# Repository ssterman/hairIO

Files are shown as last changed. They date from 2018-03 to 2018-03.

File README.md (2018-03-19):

# HairIO

Human hair is a cultural material, with a rich history displaying individuality, cultural expression and group identity.  It is malleable in length,  color and style,  highly visible,  and embedded in a range of personal and group interactions. As wearable technologies move ever closer to the body, and embodied interactions become more common and desirable, hair presents a unique and little-explored site for novel interactions. In this paper, we present an exploration and working prototype of hair as a site for novel interaction, leveraging its position as something both public and private,  social and personal, malleable and permanent. We develop applications and interactions around this new material in HäirIÖ: a novel integration of hair-based technologies and braids that combine capacitive touch input and dynamic output through color and shape change. Finally, we evaluate this hair-based interactive technology with users, including the integration of HäirIÖ within the landscape of existing wearable and mobile technologies.

Work by: Christine Dierk, Sarah Sterman, Molly Jane Nicholas, Eric Paulos

Hybrid Ecologies Lab
hybrid-ecologies.org

[Video](https://www.youtube.com/watch?v=8JV2D7gJ5HI)

[Paper](https://dl.acm.org/citation.cfm?id=3173232)

## Arduino sketches

In this repo you will find example sketches for use on the HairIO PCB, demonstrating capacitive touch, actuation, and bluetooth control.  

*demo_captouch:* A basic sketch showing only capacitive touch sensing with manually defined sensing thresholds. The onboard LED will light when a touch is identified.

*demo_timing*: A basic sketch showing only actuation.  Every period of x seconds, the braid will actuate, then turn off.  The onboard LED will light when the braid is actuating.

*demo_pcb_bluetooth_with_drive_captouch*: All-inclusive demo that uses the Adafruit Bluetooth app to provide touch feedback and control actuation through the bluetooth chip. 

All hardware pins are defined assuming the PCB version of the HairIO circuit, though all pin mappings should be double-checked when you make your own hardware. 

## Eagle Files

In *hairio_full_3* you will find the Eagle schematic and board file for the integrated PCB version of the HairIO circuit. 

## Instructable

For a full description of this project, please see the [Instructable](https://www.instructables.com/id/HairIO-Hair-As-Interactive-Material/)

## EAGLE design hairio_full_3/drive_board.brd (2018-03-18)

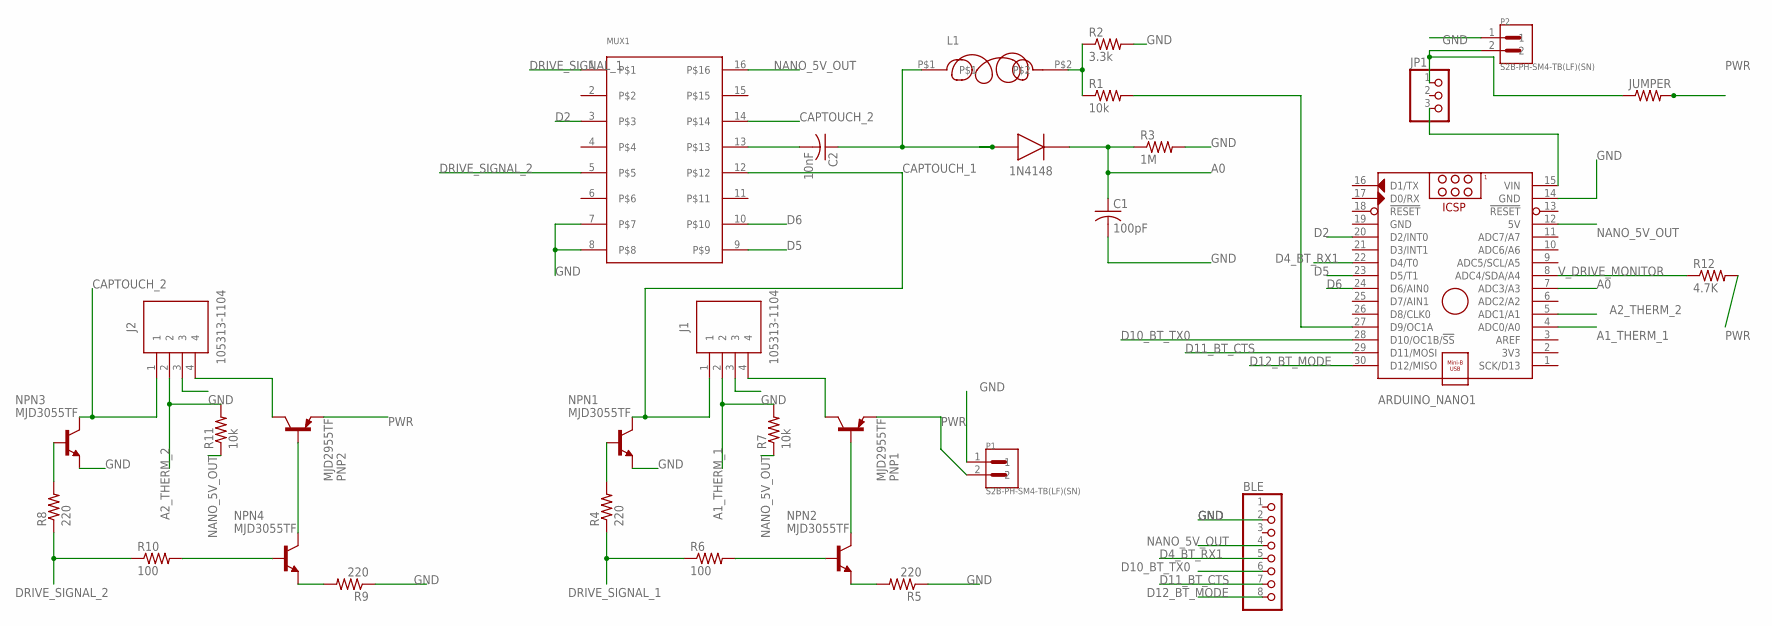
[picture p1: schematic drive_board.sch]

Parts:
1N4148: 1N5819HW-7-F; SOD3716X145N
ARDUINO_NANO1: ARDUINO_NANO
BLE: PINHD-1X8; 1X08
C1: 100pF; C0805
C2: 10nF; C0805
J1, J2: 105313-1104
JP1: PINHD-1X3; 1X03
JUMPER: R-US_R0805; R0805
L1: SRE6603
MUX1: HAIRIO_MUX; SO16
NPN1, NPN2, NPN3, NPN4: MJD3055TF; DPAK
P1, P2: S2B-PH-SM4-TB(LF)(SN); JST_S2B-PH-SM4-TB(LF)(SN)
PNP1, PNP2: MJD2955TF; DPAK
R1, R7, R11: 10k; R0805
R2: 3.3k; R0805
R3: 1M; R0805
R4, R5, R8, R9: 220; R0805
R6, R10: 100; R0805
R12: 4.7K; R0805

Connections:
A0: 1N4148.1 (K), ARDUINO_NANO1.7 (ADC3/A3), C1.1, R3.1
A1_THERM_1: ARDUINO_NANO1.4 (ADC0/A0), J1.2, R7.2
A2_THERM_2: ARDUINO_NANO1.5 (ADC1/A1), J2.2, R11.2
CAPTOUCH_1: J1.1, MUX1.12, NPN1.4 (C)
CAPTOUCH_2: J2.1, MUX1.14, NPN3.4 (C)
D2: ARDUINO_NANO1.20 (D2/INT0), MUX1.3
D4_BT_RX1: ARDUINO_NANO1.22 (D4/T0), BLE.5
D5: ARDUINO_NANO1.23 (D5/T1), MUX1.9
D6: ARDUINO_NANO1.24 (D6/AIN0), MUX1.10
D10_BT_TX0: ARDUINO_NANO1.28 (D10/OC1B/!SS), BLE.6
D11_BT_CTS: ARDUINO_NANO1.29 (D11/MOSI), BLE.7
D12_BT_MODE: ARDUINO_NANO1.30 (D12/MISO), BLE.8
DRIVE_SIGNAL_1: MUX1.1, R4.1, R6.1
DRIVE_SIGNAL_2: MUX1.5, R8.1, R10.1
GND: ARDUINO_NANO1.14 (GND), ARDUINO_NANO1.19 (GND), BLE.2, C1.2, J1.3, J2.3, MUX1.7, MUX1.8, NPN1.3 (E), NPN3.3 (E), P1.1, P2.1, R2.2, R3.2, R5.1, R9.1
unnamed: NPN2.1 (B), R6.2
unnamed: NPN2.3 (E), R5.2
unnamed: NPN4.1 (B), R10.2
unnamed: NPN2.4 (C), PNP1.1 (B)
unnamed: NPN1.1 (B), R4.2
unnamed: C2.2, MUX1.13
unnamed: 1N4148.2 (A), C2.1, L1.P$1
unnamed: J1.4, PNP1.4 (C)
unnamed: ARDUINO_NANO1.27 (D9/OC1A), R1.2
unnamed: L1.P$2, R1.1, R2.1
unnamed: NPN4.3 (E), R9.2
unnamed: ARDUINO_NANO1.15 (VIN), JP1.3
unnamed: NPN4.4 (C), PNP2.1 (B)
unnamed: NPN3.1 (B), R8.2
unnamed: J2.4, PNP2.4 (C)
unnamed: JP1.1, JUMPER.1, P2.2
NANO_5V_OUT: ARDUINO_NANO1.12 (5V), BLE.4, MUX1.16, R7.1, R11.1
PWR: JUMPER.2, P1.2, PNP1.3 (E), PNP2.3 (E), R12.2
V_DRIVE_MONITOR: ARDUINO_NANO1.8 (ADC4/SDA/A4), R12.1

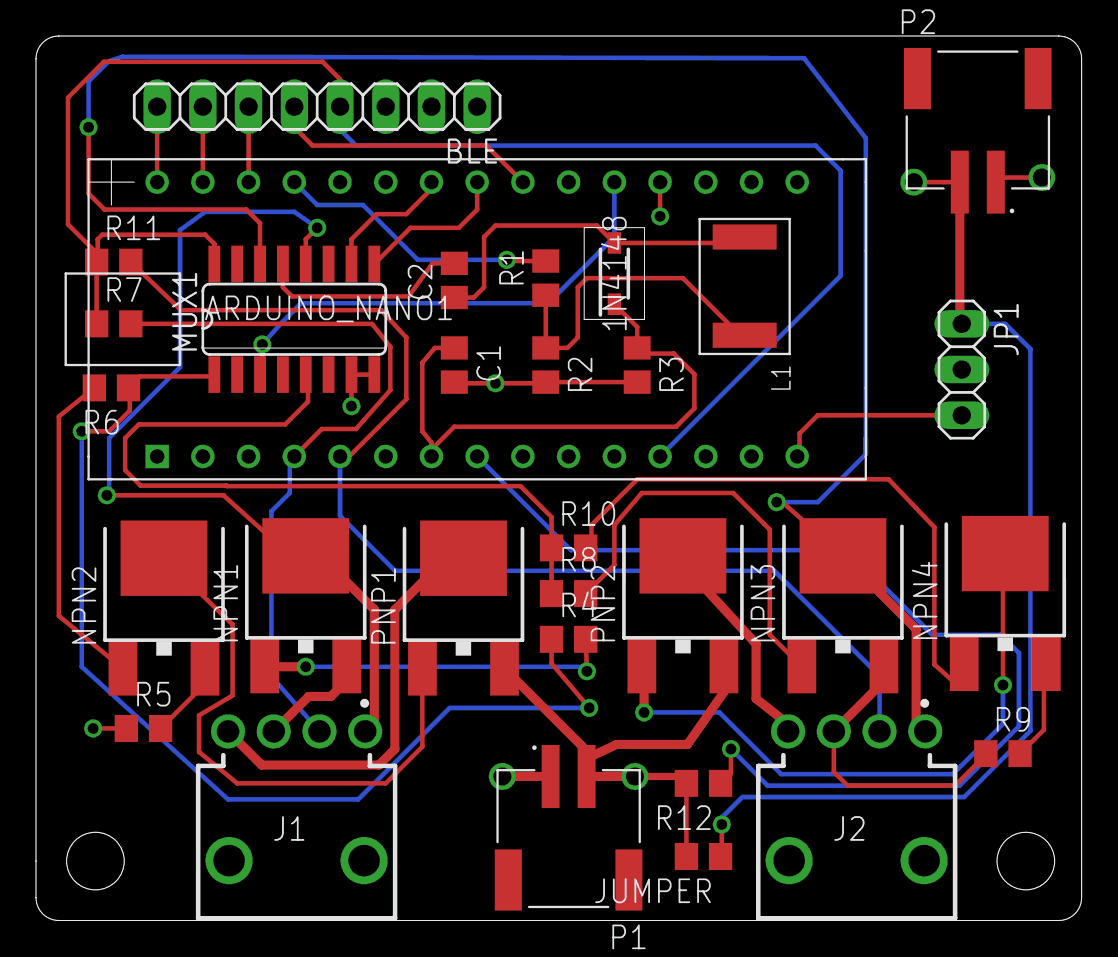
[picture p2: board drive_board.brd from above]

Board: 2 copper layers, 58.1 x 49.1 mm, 31 parts (0 on the bottom side), 34 nets.

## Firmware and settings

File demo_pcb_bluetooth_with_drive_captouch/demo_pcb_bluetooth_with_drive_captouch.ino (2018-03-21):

 /**
 * Demo code for bluetooth enabled PCB
 * ***********************************
 * Uses Bluefruit app on phone to receive captouch signals and toggle driving
 * Handles two channels of input and output
 * Monitors temperature via thermistor; includes drive shutoff if temperature threshold exceeded
 * Monitors battery voltages; warning light and drive shutoff if voltages below threshold
 */

//****************************************************************************************
// Adapted from https://github.com/Illutron/AdvancedTouchSensing
// Moves the gesture analysis from Processing to run entirely on Arduino, with fixed thresholds
// July 21 2017
//
//Added Bluetooth code adapted from Adafruit nRF51822 Bluefruit  source code
//****************************************************************************************
//****************************************************************************************
// Illutron take on Disney style capacitive touch sensor using only passives and Arduino
// Dzl 2012
//****************************************************************************************


//                              10n
// PIN 9 --[10k]-+-----10mH---+--||-- OBJECT
//               |            |
//              3.3k          |
//               |            V 1N4148 diode
//              GND           |
//                            |
//Analog 0 ---+------+--------+
//            |      |
//          100pf   1MOmhm
//            |      |
//           GND    GND

#include <Arduino.h>
#if not defined (_VARIANT_ARDUINO_DUE_X_) && not defined (_VARIANT_ARDUINO_ZERO_)
  #include <SoftwareSerial.h>
#endif

#include "Adafruit_BLE.h"
#include "Adafruit_BluefruitLE_UART.h"
#include "BluefruitConfig.h"
#include <EEPROM.h>


/**
 * capacitive touch definitions
 */
#define SET(x,y) (x |=(1<<y))        //-Bit set/clear macros
#define CLR(x,y) (x &= (~(1<<y)))           // |
#define CHK(x,y) (x & (1<<y))               // |
#define TOG(x,y) (x^=(1<<y))                //-+
#define N 160  //How many frequencies

/**
 * hardware pins
 */
#define muxApin 6
#define muxBpin 5
#define CAPTOUCHPIN A3
#define driveSignalPin 2 // drive circuit signal pin
#define voltageMonitorPin A4 //analog pin for monitoring the drive battery
#define onboardLED 13

/**
 * thermistor specific constants
 */
#define THERMISTORNOMINAL 10000 //resistance at 25 degrees C
#define TEMPERATURENOMINAL 25 // temperature for nominal resistance
#define NUMSAMPLES 5 //how many samples to take before averaging the temperature
#define BCOEFFICIENT 3950 //beta coefficient of the thermistory
#define SERIESRESISTOR 10000 //value of 'other' resistor
#define TEMPTHRESHOLD 28.0

/**
 * voltage thresholds for batteries
 */
#define SAFE_DRIVE_VOLTAGE_THRESHOLD 3.5
#define SAFE_CONTROL_VOLTAGE_THRESHOLD 5

/**
 * pins specific to a particular braid
 * are stored in a braidx object
 * the channel on the mux is set by the state of the
 * A and B select channels; the relevant states are saved 
 * in the braid object.
 * ch0 = A0B0
 * ch1 = A1B0
 */
struct braidx {
  int muxSelectA;
  int muxSelectB;
  int thermPin;
  String name_message;
  float gesturePoints[2][2];
  int eeprom_start_addr;
};

struct index_val {
  int index;
  int val;
};

/**
 * hardware has two braid channels
 */ 
struct braidx braid0 = {0, 0, A0, "Braid 0", { {0,0}, {0,0} }, 0}; //left
struct braidx braid1 = {1, 0, A1, "Braid 1", { {0,0}, {0,0} }, 8}; //right
struct braidx currentBraid = braid0;

/**
 * Bluetooth setup
 * Create the bluefruit object in software serial
 */
SoftwareSerial bluefruitSS = SoftwareSerial(BLUEFRUIT_SWUART_TXD_PIN, BLUEFRUIT_SWUART_RXD_PIN);

Adafruit_BluefruitLE_UART ble(bluefruitSS, BLUEFRUIT_UART_MODE_PIN,
                      BLUEFRUIT_UART_CTS_PIN, BLUEFRUIT_UART_RTS_PIN);


/**
 * Gesture sensing and processing variables
 */
//Gesture sensing variables
int results[N];            //-Filtered result buffer
int freq[N];            //-Filtered result buffer
int sizeOfArray = N;

//Gesture processing variables
int gestureDist[2];
String names[2] = {"nothing", "touch"};

char curGesture = 0;
char lastGesture = 0;

//so that we don't send "braid touched" while drive circuit is running
bool driving = false; 

/****************************************
 * End of variable set up
 ****************************************/

void setup()
{ 
  Serial.begin(9600);
  Serial.println("touch_sensing_bluefruit_v2 edited February 22th, 2018");
  
  TCCR1A = 0b10000010;      //-Set up frequency generator
  TCCR1B = 0b00011001;      //-+
  ICR1 = 110;
  OCR1A = 55;

  pinMode(9, OUTPUT);       //-Signal generator pin
  pinMode(8, OUTPUT);       //-Sync (test) pin
  pinMode(muxApin, OUTPUT);
  pinMode(muxBpin, OUTPUT);
  pinMode(driveSignalPin, OUTPUT);
  pinMode(onboardLED, OUTPUT);

  // initialize results array to all zeros
  memset(results,0,sizeof(results));

  ble.begin();

  /* Disable command echo from Bluefruit */
  ble.echo(false);

  ble.info();
  
  /* Wait for connection */
  while (! ble.isConnected()) {
      delay(500);
  }

  // Set module to DATA mode
  //Serial.println( F("Switching to DATA mode!") );
  ble.setMode(BLUEFRUIT_MODE_DATA);

  //set mux pins according to braid's channel select parameters
  digitalWrite(muxApin, currentBraid.muxSelectA);
  digitalWrite(muxBpin, currentBraid.muxSelectB);

  setGestureThresholds(&braid0);
  setGestureThresholds(&braid1);
}

void setGestureThresholds(struct braidx * braid) {
  //original set values:  34x, 390y; 50x; 300y;

  //no touch
  braid->gesturePoints[0][0] = (unsigned int) EEPROM.read(braid->eeprom_start_addr + 0) + ((unsigned int) EEPROM.read(braid->eeprom_start_addr + 1) << 8);   //x coord
  braid->gesturePoints[0][1] = (unsigned int) EEPROM.read(braid->eeprom_start_addr + 2) + ((unsigned int) EEPROM.read(braid->eeprom_start_addr + 3) << 8);  //y coord
  
  //touch
   braid->gesturePoints[1][0] = (unsigned int) EEPROM.read(braid->eeprom_start_addr + 4) + ((unsigned int) EEPROM.read(braid->eeprom_start_addr + 5) << 8);  //x coord
   braid->gesturePoints[1][1] = (unsigned int) EEPROM.read(braid->eeprom_start_addr + 6) + ((unsigned int) EEPROM.read(braid->eeprom_start_addr + 7) << 8);  //y coord
  Serial.println("Braid No Touch");
  Serial.println(braid->gesturePoints[0][0]);
  Serial.println(braid->gesturePoints[0][1]);
  Serial.println("Braid Touch");
  Serial.println(braid->gesturePoints[1][0]);
  Serial.println(braid->gesturePoints[1][1]);
}


void processGesture() {
  if ((curGesture == 1) & (driving == false)){
    String s = " touched";
    uint8_t sendbuffer[20];
    s.getBytes(sendbuffer, 20);
    char sendbuffersize = min(20, s.length());

    ble.write(sendbuffer, sendbuffersize);
    Serial.println(s);
  }
}

void sendBLEMessage(String msg) {
  uint8_t sendbuffer[20];
  msg.getBytes(sendbuffer, 20);
  char sendbuffersize = min(20, msg.length());

  ble.write(sendbuffer, sendbuffersize);
}

//adapted from http://forum.arduino.cc/index.php?topic=41999.0
struct index_val getMaxFromArray(int* array, int size) {
  int max = array[0];
  int max_index = 0;
  for (int i = 1; i < size; i++) {
    if (max < array[i]) {
      max = array[i];
      max_index = i;
    }
  }
  struct index_val iv = {max_index, max};
  return iv;
}

//assumes no negative values for time or voltage
int dist(int x1, int y1, int x2, int y2) {

  int xmax = max(x1, x2);
  int ymax = max(y1, y2);

  float w;
  if (x1 > x2) {
    w = x1 - x2;
  } else {
    w = x2 - x1;
  }
  float h;
  if (y1 > y2) {
    h = y1 - y2;
  } else {
    h = y2 - y1;
  }
  
  int intVal = (int) sqrt(h*h + w*w);
  return intVal;
}

void analyzeInput(int timeArr[], int voltageArr[]) {

  /* ====================================================================
    Gesture compare
    ====================================================================  */
  int currentMax = 0;
  int currentMaxValue = -1;
  for (int i = 0; i < 2; i++)
  {
    //calculate individual dist
    struct index_val iv = getMaxFromArray(voltageArr, N);
    gestureDist[i] = dist(iv.index, iv.val, currentBraid.gesturePoints[i][0], currentBraid.gesturePoints[i][1]);
    if (gestureDist[i] < currentMaxValue || i == 0)
    {
      currentMax = i;
      currentMaxValue =  gestureDist[i];
    }
  }

  int type = currentMax;
  lastGesture = curGesture;
  curGesture = type;
}


// read temp and write to serial monitor
// return temp
int readThermistor() {
    uint8_t i;
    float average;
    uint16_t samples[NUMSAMPLES];

    //take N samples in a row, with a slight delay
  
    for (i = 0; i < NUMSAMPLES; i++) {
      samples[i] = analogRead(currentBraid.thermPin);
      delay(10);
    }
  
    // average all the samples out
    average = 0;
    for (i = 0; i < NUMSAMPLES; i++) {
      average += samples[i];
    }
    average /= NUMSAMPLES;
  
    //convert these values to resistance
    average = 1023 / average - 1;
    average = SERIESRESISTOR / average;
  
    //convert these values to temperature
    average = average / THERMISTORNOMINAL;
    average = log(average);
    average /= BCOEFFICIENT;
    average += 1.0 / (TEMPERATURENOMINAL + 273.15);
    average = 1.0 / average;
    average -= 273.15;
  
    //average is now the temperature of the thermistor
    return average;
}

//If the temperature is above the threshold,
//turn off driving
void thermistorThrottle(float temp) {
    if (temp >= TEMPTHRESHOLD) {
        turnOffDrive();
    }
}

void capacitiveSweep() {
  for (unsigned int d = 0; d < N; d++)
  {
    int v = analogRead(CAPTOUCHPIN);  //-Read response signal
    CLR(TCCR1B, 0);         //-Stop generator
    TCNT1 = 0;              //-Reload new frequency
    ICR1 = d;               // |
    OCR1A = d / 2;          //-+
    SET(TCCR1B, 0);         //-Restart generator

    int testVal = results[d] * 0.5 + v*0.5;
    results[d] = testVal;
    //results[d] = results[d] * 0.5 + (float)(v) * 0.5; //Filter results
    freq[d] = d;

    //   plot(v,0);              //-Display
    //   plot(results[d],1);
    // delayMicroseconds(1);
  }
}

//https://provideyourown.com/2012/secret-arduino-voltmeter-measure-battery-voltage/
long readVcc() {
  // Read 1.1V reference against AVcc
  // set the reference to Vcc and the measurement to the internal 1.1V reference
  #if defined(__AVR_ATmega32U4__) || defined(__AVR_ATmega1280__) || defined(__AVR_ATmega2560__)
    ADMUX = _BV(REFS0) | _BV(MUX4) | _BV(MUX3) | _BV(MUX2) | _BV(MUX1);
  #elif defined (__AVR_ATtiny24__) || defined(__AVR_ATtiny44__) || defined(__AVR_ATtiny84__)
    ADMUX = _BV(MUX5) | _BV(MUX0);
  #elif defined (__AVR_ATtiny25__) || defined(__AVR_ATtiny45__) || defined(__AVR_ATtiny85__)
    ADMUX = _BV(MUX3) | _BV(MUX2);
  #else
    ADMUX = _BV(REFS0) | _BV(MUX3) | _BV(MUX2) | _BV(MUX1);
  #endif  

  delay(2); // Wait for Vref to settle
  ADCSRA |= _BV(ADSC); // Start conversion
  while (bit_is_set(ADCSRA,ADSC)); // measuring

  uint8_t low  = ADCL; // must read ADCL first - it then locks ADCH  
  uint8_t high = ADCH; // unlocks both

  long result = (high<<8) | low;

  result = 1125300L / result; // Calculate Vcc (in mV); 1125300 = 1.1*1023*1000
  return result; // Vcc in millivolts
}


/*
 * Monitor the state of the batteries.
 * Light the onboard LED if the battery is low
 * TODO: need a way to distinguish which one is low
 */
void monitorBatteries() {
  int driveSensorValue = analogRead(voltageMonitorPin);
  float driveVoltage= driveSensorValue * (3.7 / 1023.0);

  Serial.println(driveVoltage);
  if (driveVoltage < SAFE_DRIVE_VOLTAGE_THRESHOLD) {
      turnOffDrive();
      digitalWrite(onboardLED, HIGH);
  }
  long controlVoltageMillivolts = readVcc();
  float controlVoltage = controlVoltageMillivolts/1000.0;
  Serial.println(controlVoltage);
  if (controlVoltage < SAFE_CONTROL_VOLTAGE_THRESHOLD) {
      digitalWrite(onboardLED, HIGH);
  }
}

void turnOnDrive() {
   digitalWrite(driveSignalPin, HIGH);
   driving = true;
//   Serial.println(currentBraid.name_message + "Driving...");
   sendBLEMessage("Driving \n");
}

void turnOffDrive() {       
   reset_mux(braid0);
   digitalWrite(driveSignalPin, LOW);
   reset_mux(braid1);
   digitalWrite(driveSignalPin, LOW);
   driving = false;
   sendBLEMessage("Not driving \n");
}

void do_captouch(){
   //update the captouch state
  capacitiveSweep();
  
  //this would send the data to processing
//  PlottArray(1,freq,results);

  // instead of sending to processing, do the work here
  analyzeInput(freq, results);
  processGesture();

}

void calibrate_captouch(struct braidx * braid) {  
  reset_mux(*braid);
  
  delay(2000); //time to read instructions
  sendBLEMessage("\n\n\n");
  sendBLEMessage("Calibrating....");
  sendBLEMessage("please hold braid ");
  sendBLEMessage(" for 5 seconds...");
 
  delay(2500); //time to obey instructions
  
  capacitiveSweep();
  struct index_val iv = getMaxFromArray(results, N);
  int ycoord = iv.val;
  int xcoord = iv.index;
  
  //store to eeprom
  EEPROM.write(braid->eeprom_start_addr + 4, xcoord); //touch
  EEPROM.write(braid->eeprom_start_addr + 5, xcoord >>8); 

  EEPROM.write(braid->eeprom_start_addr + 6, ycoord); //touch
  EEPROM.write(braid->eeprom_start_addr + 7, ycoord >>8);

  delay(2500);
  sendBLEMessage("\n\n\n");
  sendBLEMessage("Release braid...");
  sendBLEMessage("for 5 seconds");
  sendBLEMessage(" without ");
  sendBLEMessage("touching....");

  delay(2500);
  capacitiveSweep();
  iv = getMaxFromArray(results, N);
  ycoord = iv.val;
  xcoord = iv.index;
  EEPROM.write(braid->eeprom_start_addr + 0, xcoord); //no touch
  EEPROM.write(braid->eeprom_start_addr + 1, xcoord >>8); 

  EEPROM.write(braid->eeprom_start_addr + 2, ycoord); //no touch
  EEPROM.write(braid->eeprom_start_addr + 3, ycoord >>8);
    
  setGestureThresholds(braid);

  delay(2500);
}


void reset_mux(struct braidx newbraid){
  currentBraid = newbraid;
  digitalWrite(muxApin, currentBraid.muxSelectA);
  digitalWrite(muxBpin, currentBraid.muxSelectB);
}


//listen to both braids during each loop
//but only if no braid is actuating
//only allow one actuation at a time
//if new actuation is pressed, overrride the current state
// off press if off does nothing
// can't read captouch unless off

void loop()
{
  if (!driving) {
    reset_mux(braid0);
    do_captouch();
  
    reset_mux(braid1);
    do_captouch();
  }

  String received = "";
  
  // Check to see if received toggle from Phone
  //https://learn.adafruit.com/bluefruit-le-connect-for-ios/controller
  while ( ble.available() )
  {
    int c = ble.read();
    received = received + (char) c;
    if (received.equals("!B10;") || received.equals("0")){        
        turnOffDrive();   //both off
        reset_mux(braid0);
        turnOnDrive();    //turn the hair0 drive on
    } else if (received.equals("!B20") || received.equals("1")){
        turnOffDrive();  //both off
        reset_mux(braid1);
        turnOnDrive();   //turn the hair1 drive on
    } else if (received.equals("!B30") || received.equals("!B40") || received.equals("x")){ 
        turnOffDrive(); //turn all drive off
    } else if (received.equals("c")) { // send via the UART control panel
      sendBLEMessage("\n\n\n");
      sendBLEMessage("Ready to calibrate");
      sendBLEMessage(": touch braid 0 ");
       calibrate_captouch(&braid0);
      sendBLEMessage("\n\n\n");
      sendBLEMessage("Ready to calibrate");
      sendBLEMessage(": touch braid 1 ");
       calibrate_captouch(&braid1);
      sendBLEMessage("\n\n\n");
      sendBLEMessage("Calibration done");
    }
  }
  
  if (driving) {
      float temp = readThermistor();
      thermistorThrottle(temp); //turn it off if temp is too high
  }

  monitorBatteries();

  TOG(PORTB, 0);           //-Toggle pin 8 after each sweep (good for scope)
}

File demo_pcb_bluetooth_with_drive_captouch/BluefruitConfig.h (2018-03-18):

// COMMON SETTINGS
// ----------------------------------------------------------------------------------------------
// These settings are used in both SW UART, HW UART and SPI mode
// ----------------------------------------------------------------------------------------------
#define BUFSIZE                        128   // Size of the read buffer for incoming data
#define VERBOSE_MODE                   true  // If set to 'true' enables debug output


// SOFTWARE UART SETTINGS
// ----------------------------------------------------------------------------------------------
// The following macros declare the pins that will be used for 'SW' serial.
// You should use this option if you are connecting the UART Friend to an UNO
// ----------------------------------------------------------------------------------------------
#define BLUEFRUIT_SWUART_RXD_PIN       4    // Required for software serial!
#define BLUEFRUIT_SWUART_TXD_PIN       10   // Required for software serial!
#define BLUEFRUIT_UART_CTS_PIN         11   // Required for software serial!
#define BLUEFRUIT_UART_RTS_PIN         -1   // Optional, set to -1 if unused


// HARDWARE UART SETTINGS
// ----------------------------------------------------------------------------------------------
// The following macros declare the HW serial port you are using. Uncomment
// this line if you are connecting the BLE to Leonardo/Micro or Flora
// ----------------------------------------------------------------------------------------------
#ifdef Serial1    // this makes it not complain on compilation if there's no Serial1
  #define BLUEFRUIT_HWSERIAL_NAME      Serial1
#endif


// SHARED UART SETTINGS
// ----------------------------------------------------------------------------------------------
// The following sets the optional Mode pin, its recommended but not required
// ----------------------------------------------------------------------------------------------
#define BLUEFRUIT_UART_MODE_PIN        12    // Set to -1 if unused


// SHARED SPI SETTINGS
// ----------------------------------------------------------------------------------------------
// The following macros declare the pins to use for HW and SW SPI communication.
// SCK, MISO and MOSI should be connected to the HW SPI pins on the Uno when
// using HW SPI.  This should be used with nRF51822 based Bluefruit LE modules
// that use SPI (Bluefruit LE SPI Friend).
// ----------------------------------------------------------------------------------------------
#define BLUEFRUIT_SPI_CS               8
#define BLUEFRUIT_SPI_IRQ              7
#define BLUEFRUIT_SPI_RST              -1    // Optional but recommended, set to -1 if unused

// SOFTWARE SPI SETTINGS
// ----------------------------------------------------------------------------------------------
// The following macros declare the pins to use for SW SPI communication.
// This should be used with nRF51822 based Bluefruit LE modules that use SPI
// (Bluefruit LE SPI Friend).
// ----------------------------------------------------------------------------------------------
#define BLUEFRUIT_SPI_SCK              13
#define BLUEFRUIT_SPI_MISO             12
#define BLUEFRUIT_SPI_MOSI             11
